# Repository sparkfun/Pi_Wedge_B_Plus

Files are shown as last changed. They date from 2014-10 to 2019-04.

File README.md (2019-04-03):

**NOTE:** *This product has been retired from our catalog. For the latest version, check out [BOB-13717](https://www.sparkfun.com/products/13717).*

*If you are looking for more up-to-date info, please check out some of these resources to see how other users are still hacking and improving on this version of the product.*
* *[SparkFun Forum](https://forum.sparkfun.com/)*
* *[Comments Here on GitHub](https://github.com/sparkfun/Pi_Wedge_B_Plus/issues)*
* *[IRC Channel](https://www.sparkfun.com/news/263)*

Pi Wedge B Plus - Breakout For Raspberry Pi B+ GPIO Connector
----------------------------

_Syntactic note: Guthub didn't like the '+' character in the name, so it's spelled out, instead._ 

----------------------------

(https://www.sparkfun.com/products/retired/13091)

This is the Pi Wedge B Plus, a board that connects to the Raspberry Pi B+’s 40-pin GPIO connector, and breaks the pins out to breadboard-friendly arrangement and spacing, and even adds a couple of decoupling capacitors on the power supply lines. The “Wedge” also makes the initial bringup process easier - you can plug an FTDI Basic module into the built-in serial port. Each Pi Wedge comes as an easy to assemble kit that can can be inserted into the Raspberry Pi’s GPIO port that allows you to prototype as soon as you are done soldering.

The kit works with both the Model A+ and [Model B+](https://www.sparkfun.com/products/11546) versions of the Raspberry Pi.

For the Model A and Model B, we also offer the regular [Pi Wedge](https://www.sparkfun.com/products/12652) 

It adapts the GPIO header on the B+ to a standard solderless breadboard, such as our [meduim](https://www.sparkfun.com/products/12002), [large](https://www.sparkfun.com/products/112) and [extra large](https://www.sparkfun.com/products/12614) breadboards.  While it will technically with with a [mini](https://www.sparkfun.com/products/12043) breadboard, it won't leave much room for external circuitry.

More information can be found on the [Pi Wedge B+ product Page](https://www.sparkfun.com/products/12994), and in the [Pi Wedge B+ hookup guide](https://learn.sparkfun.com/tutorials/pi-wedge-b-hookup-guide).

This part was created in Eagle v6.5.0.  Software examples were developed using the [WiringPi](wiringpi.com) libraries and utilities.

Repository Contents
-------------------

* **/Hardware** - All Eagle design files (.brd, .sch, .STL)
* **/Software** - C source code for SPI, I2C and GPIO examples.  All use [WiringPi](wiringpi.com) for the underlying device interfaces

Documentation
--------------

* **[Hookup Guide](https://learn.sparkfun.com/tutorials/retired---pi-wedge-b-hookup-guide)** - Basic hookup guide
* **[Raspberry gPIo](https://learn.sparkfun.com/tutorials/raspberry-gpio)** - Programming guide using the Pi's I/O pins with Python and C. 
* **[Raspberry Pi SPI and I2C Tutorial](https://learn.sparkfun.com/tutorials/raspberry-pi-spi-and-i2c-tutorial)** - Programming guide using the Pi's SPI and I2C.

Product Versions
----------------
* [V1.1](https://www.sparkfun.com/products/retired/13091)- Pi Wedge B+ kit

Version History
---------------

* [820b901aa31b3c76c1dbefd9966a04860c9f83ca](https://github.com/sparkfun/Pi_Wedge_B_Plus/commit/820b901aa31b3c76c1dbefd9966a04860c9f83ca) - Initial release version.

License Information
-------------------
The hardware is released under [Creative Commons ShareAlike 4.0 International](https://creativecommons.org/licenses/by-sa/4.0/).

The code is beerware; if you see me (or any other SparkFun employee) at the local, and you've found our code helpful, please buy us a round!

Distributed as-is; no warranty is given.

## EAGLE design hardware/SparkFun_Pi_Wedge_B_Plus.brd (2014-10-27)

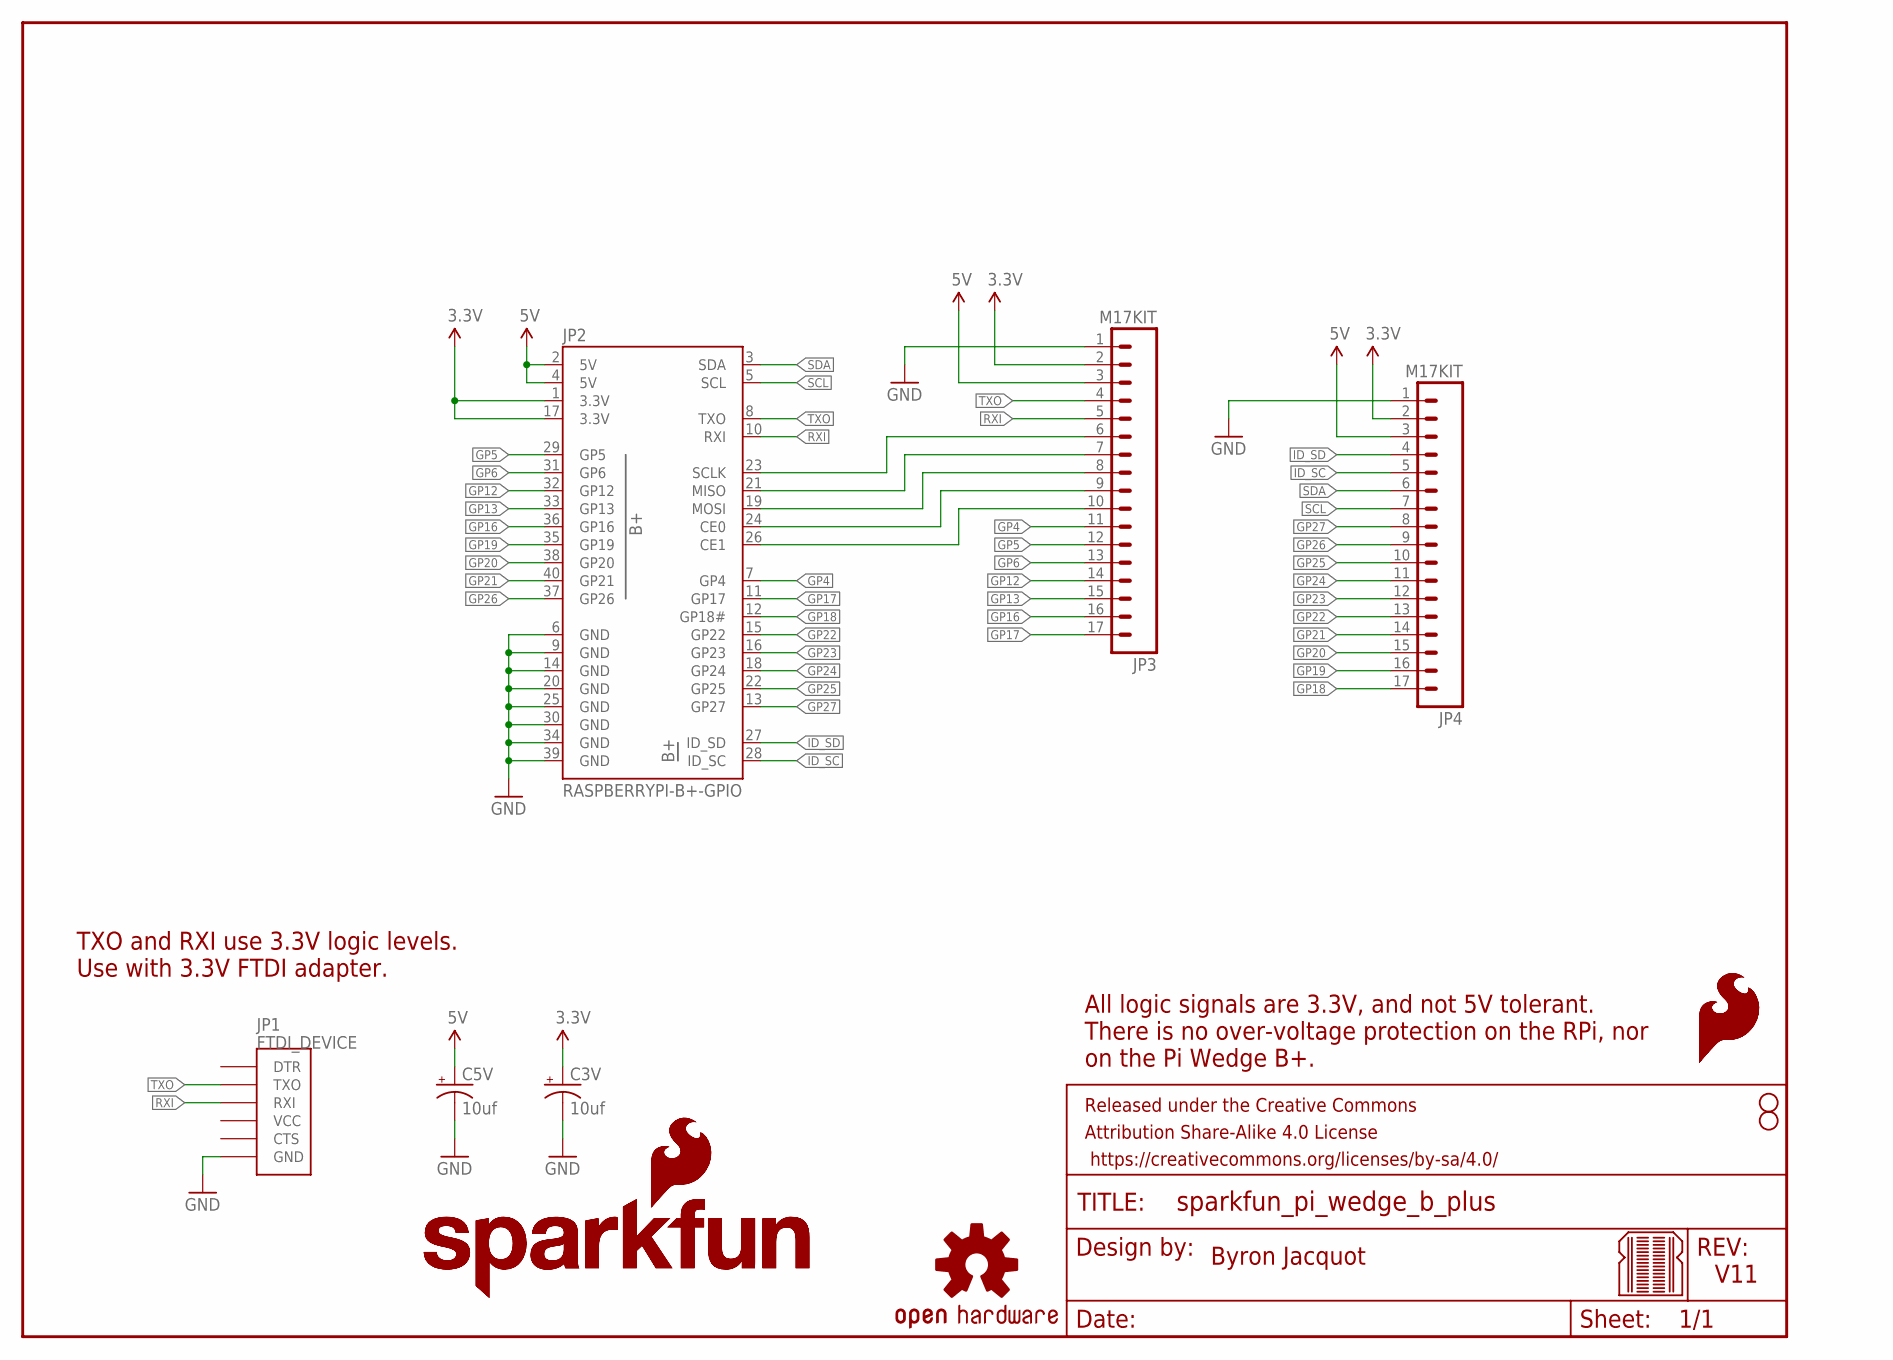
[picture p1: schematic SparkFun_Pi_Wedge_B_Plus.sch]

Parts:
C3V, C5V: 10uf; CPOL-RADIAL-10UF-25V-KIT
FRAME2: FRAME-LETTER; CREATIVE_COMMONS
JP1: FTDI_DEVICE; FTDI_DEVICE_SIDE
JP2: RASPBERRYPI-B+-GPIO; 2X20-SHROUDED
JP3, JP4: M17KIT; 1X17_NO_SILK_KIT
LOGO1, LOGO2: SFE_LOGO_NAME_FLAME.2_INCH; SFE_LOGO_NAME_FLAME_.2
LOGO3, LOGO4: SFE_LOGO_FLAME.1_INCH; SFE_LOGO_FLAME_.1
LOGO5: OSHW-LOGOS; OSHW-LOGO-S
STANDOFF1, STANDOFF2: STAND-OFF
U$2: BREADBOARD_PATTERN; BREADBOARD_SPACING

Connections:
3.3V: C3V.1 (+), JP2.1 (3.3V), JP2.17 (3.3V), JP3.2, JP4.2
5V: C5V.1 (+), JP2.2 (5V), JP2.4 (5V), JP3.3, JP4.3
CE0: JP2.24 (CE0), JP3.9
CE1: JP2.26 (CE1), JP3.10
GND: C3V.2 (-), C5V.2 (-), JP1.P$6 (GND), JP2.6 (GND), JP2.9 (GND), JP2.14 (GND), JP2.20 (GND), JP2.25 (GND), JP2.30 (GND), JP2.34 (GND), JP2.39 (GND), JP3.1, JP4.1
GP4: JP2.7 (GP4), JP3.11
GP5: JP2.29 (GP5), JP3.12
GP6: JP2.31 (GP6), JP3.13
GP12: JP2.32 (GP12), JP3.14
GP13: JP2.33 (GP13), JP3.15
GP16: JP2.36 (GP16), JP3.16
GP17: JP2.11 (GP17), JP3.17
GP18: JP2.12 (GP18#), JP4.17
GP19: JP2.35 (GP19), JP4.16
GP20: JP2.38 (GP20), JP4.15
GP21: JP2.40 (GP21), JP4.14
GP22: JP2.15 (GP22), JP4.13
GP23: JP2.16 (GP23), JP4.12
GP24: JP2.18 (GP24), JP4.11
GP25: JP2.22 (GP25), JP4.10
GP26: JP2.37 (GP26), JP4.9
GP27: JP2.13 (GP27), JP4.8
ID_SC: JP2.28 (ID_SC), JP4.5
ID_SD: JP2.27 (ID_SD), JP4.4
MISO: JP2.21 (MISO), JP3.7
MOSI: JP2.19 (MOSI), JP3.8
RXI: JP1.P$3 (RXI), JP2.10 (RXI), JP3.5
SCL: JP2.5 (SCL), JP4.7
SCLK: JP2.23 (SCLK), JP3.6
SDA: JP2.3 (SDA), JP4.6
TXO: JP1.P$2 (TXO), JP2.8 (TXO), JP3.4

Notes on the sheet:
Byron Jacquot
V11
All logic signals are 3.3V, and not 5V tolerant. There is no over-voltage protection on the RPi, nor on the Pi Wedge B+.
TXO and RXI use 3.3V logic levels. Use with 3.3V FTDI adapter.

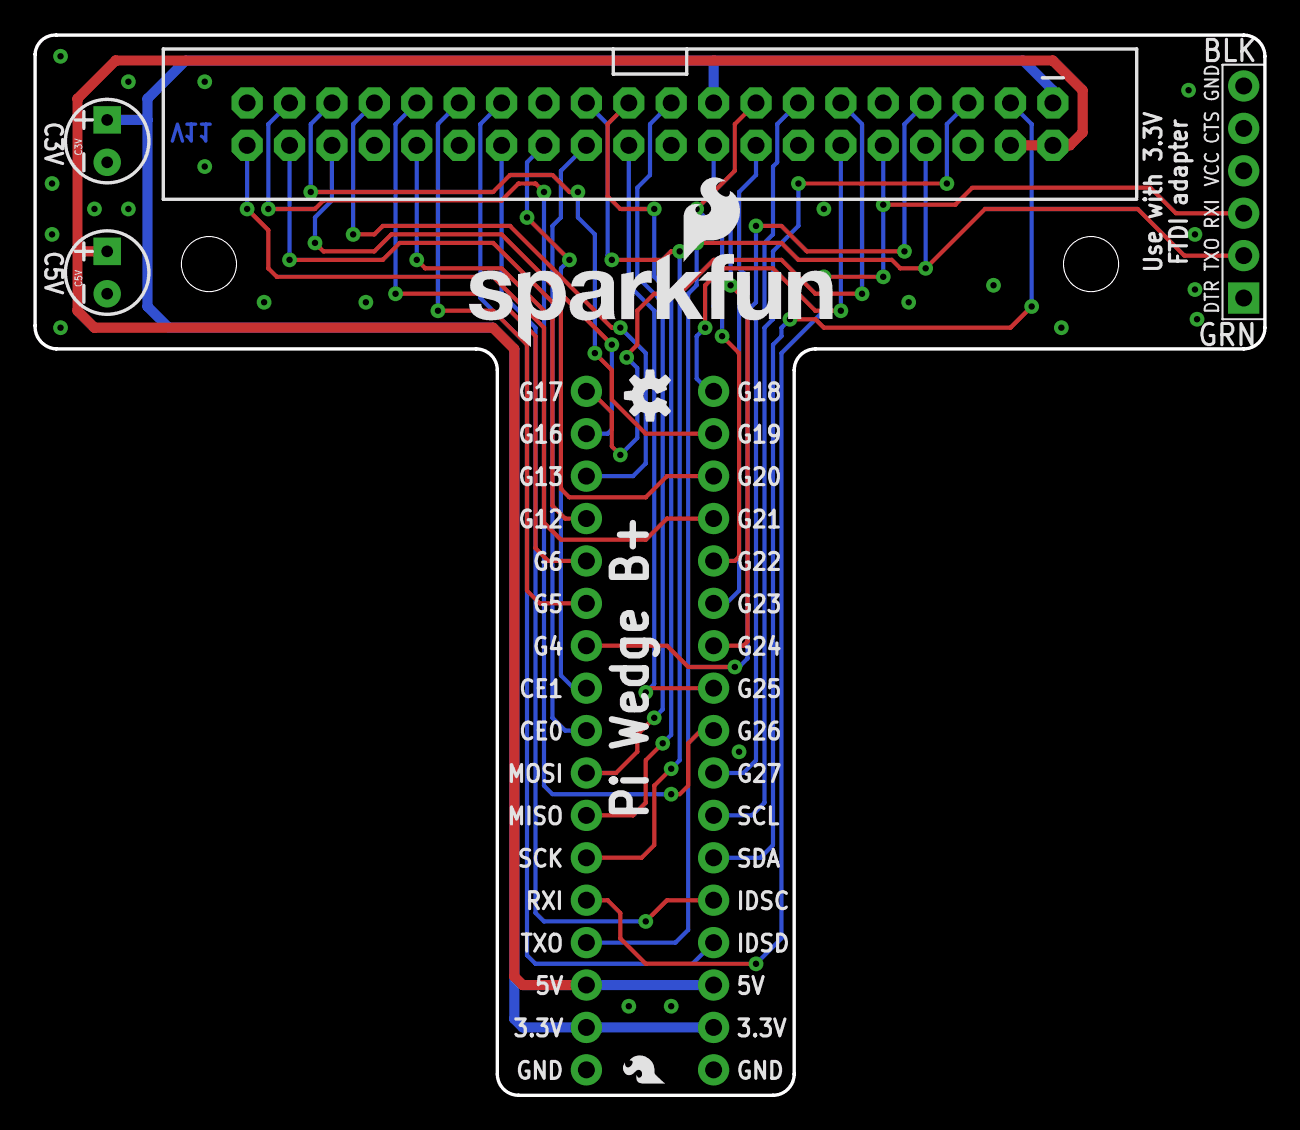
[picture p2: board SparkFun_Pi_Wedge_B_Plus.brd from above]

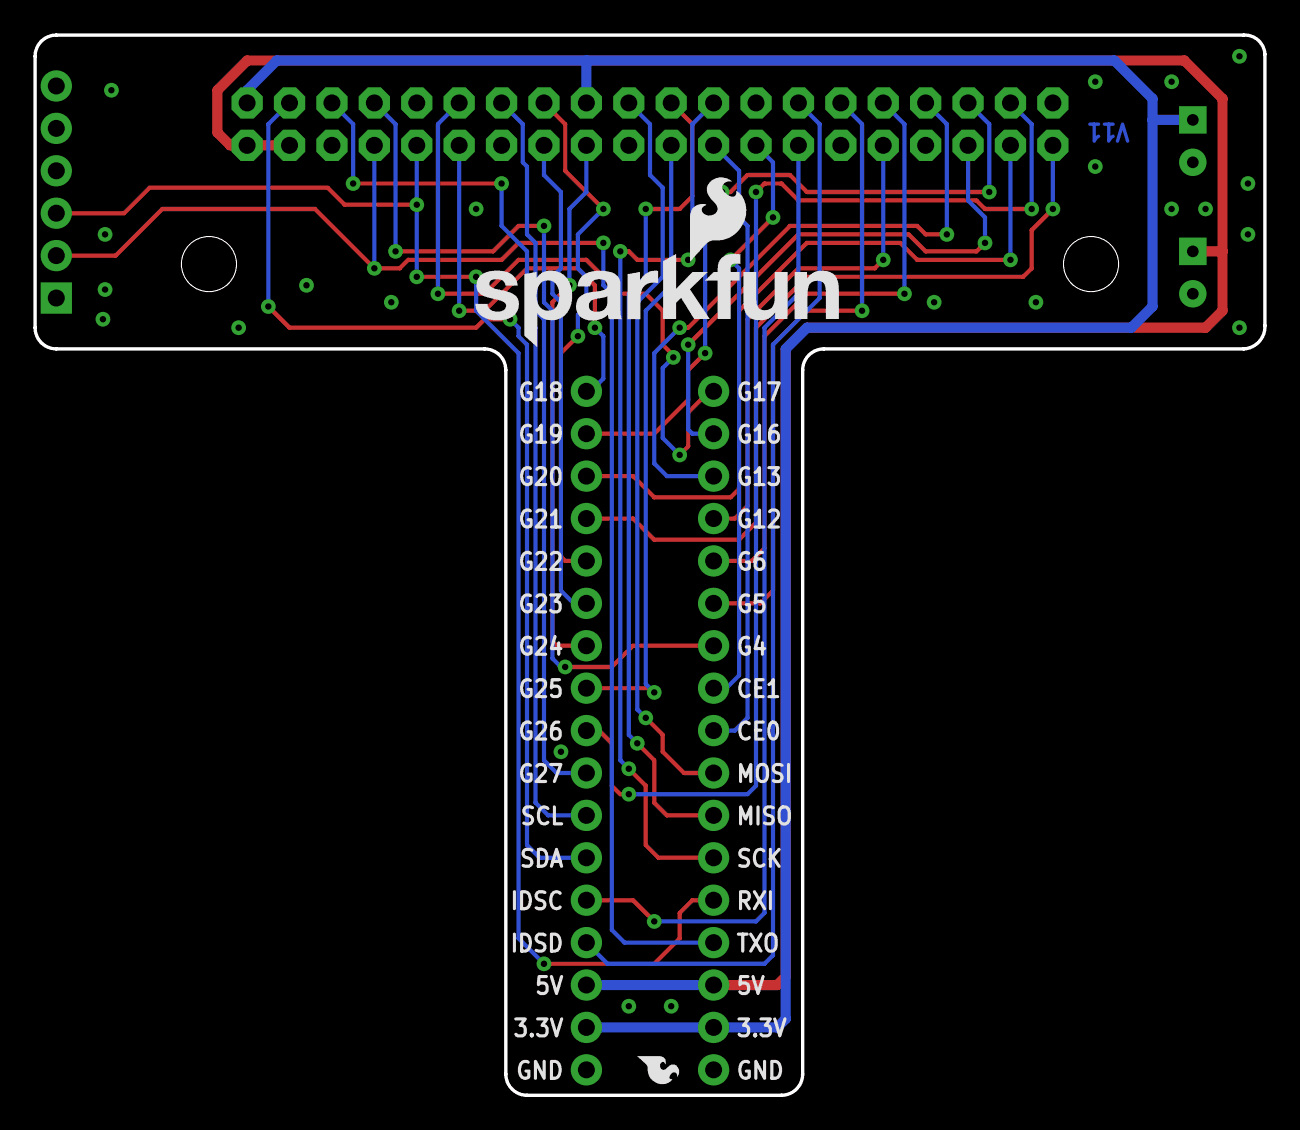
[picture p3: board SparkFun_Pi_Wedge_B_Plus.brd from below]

Board: 2 copper layers, 73.7 x 63.5 mm, 15 parts (4 on the bottom side), 31 nets.

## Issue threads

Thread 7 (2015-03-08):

'spi_bcm2708': No such device

WilHowitt, 2015-03-08:
I can build the SparkFun_spitest.cpp with no problem, but when I try to load the SPI module, I get this error:

$ gpio load spi
ERROR: could not insert 'spi_bcm2708': No such device
gpio: Unable to load spi_bcm2708

I don't know if this error is specific to this file or not . . . can you help me out?

bboyho, 2019-04-03:
Hi,

Sorry for the delay in reply. I just noticed your question when browsing the issues tab. If you have not already solved the problem, it might be due to the Pi's  image used at the time. This is probably due to the way the kernel was built when you filed the issue => [ [https://www.raspberrypi.org/forums/viewtopic.php?f=28&t=97314](https://www.raspberrypi.org/forums/viewtopic.php?f=28&t=97314). Try checking the section where it says "**Fixing the Problem**".  I found the forum link after entering the command in the Pi's command line using the latest image.

Doing a search with the error that you had, it seems to match the issue with the kernel using **spi_bcm2835.ko** as opposed to **spi_bcm,2708.ko** => [ [https://www.raspberrypi.org/forums/viewtopic.php?p=793284&sid=09141fb98ec91a5e1413def769ad257e#p793284(https://www.raspberrypi.org/forums/viewtopic.php?p=793284&sid=09141fb98ec91a5e1413def769ad257e#p793284) .

If you are still having issues, you may want to post on the [Raspberry Pi](https://www.raspberrypi.org/forums/) or the [SparkFun Forums](https://forum.sparkfun.com/viewforum.php?f=100) to see if anyone has run into this specific case.

Closed 2019-04-03.

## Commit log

2014-08-22 Initial commit
    Mostly copied from old Pi Wedge repo
    [Pi Wedge B Plus.brd, Pi Wedge B Plus.sch]
2014-08-26 Better routing.
    [Pi Wedge B Plus.brd, Pi Wedge B Plus.sch]
2014-08-27 Slight Tweaks to outline
    [Pi Wedge B Plus.brd]
2014-10-06 Bumping rev number for reds
    From V01 to V10.
    [Pi Wedge B Plus.brd, Pi Wedge B Plus.sch]
2014-10-27 Fixing kit soldermask on 17-pin headers.
    [Pi Wedge B Plus.brd]
2014-10-27 Review updates
    Based on Pete Lewis's comments.
    [Pi Wedge B Plus.brd, Pi Wedge B Plus.sch]
2014-12-18 Renaming files.
    Prepending "SparkFun_" on PCB and software files.
    [SparkFun_Pi_Wedge_B_Plus.brd, SparkFun_Pi_Wedge_B_Plus.sch]

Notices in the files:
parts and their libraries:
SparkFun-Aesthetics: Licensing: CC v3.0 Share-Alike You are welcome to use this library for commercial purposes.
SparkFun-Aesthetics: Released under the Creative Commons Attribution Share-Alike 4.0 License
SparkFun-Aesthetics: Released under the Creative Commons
